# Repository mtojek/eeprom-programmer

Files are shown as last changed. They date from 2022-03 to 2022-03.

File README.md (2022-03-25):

# eeprom-programmer
EEPROM programmer based on Arduino

This repository contains Kicad schematics and .ino source files to build the EEPROM programmer using Arduino UNO R3. If you are following the Ben's Eater course to [build a 6502 computer](https://eater.net/6502), you will see that Ben uses a [TL866 II Plus](https://eater.net/6502) model, but it is possible to program memory chips using this homebrew board.

## Sample output

Check Arduino serial monitor to see memory content:

```
Reset
Run!
0000: a9 ff 8d 02 60 a9 50 8d    00 60 6a 8d 00 60 4c 0a    ⸮⸮⸮`⸮P⸮ 
0010: 80 00 00 00 00 00 00 00    00 00 00 00 00 00 00 00    ⸮
0020: 00 00 00 00 00 00 00 00    00 00 00 00 00 00 00 00    
...
7fc0: 00 00 00 00 00 00 00 00    00 00 00 00 00 00 00 00    
7fd0: 00 00 00 00 00 00 00 00    00 00 00 00 00 00 00 00    
7fe0: 00 00 00 00 00 00 00 00    00 00 00 00 00 00 00 00    
7ff0: 00 00 00 00 00 00 00 00    00 00 00 00 00 80 00 00    
```

## Kicad preview

<p float="left">
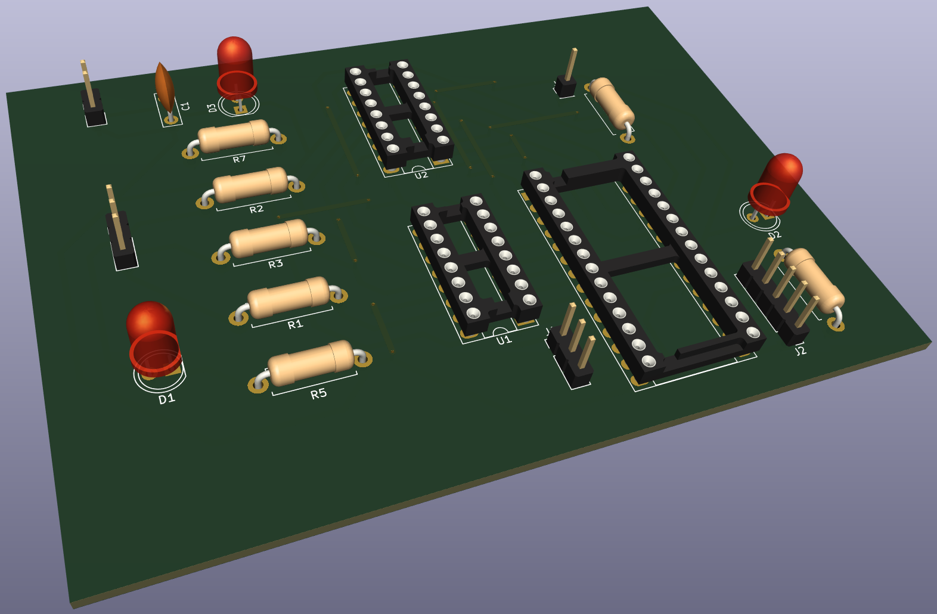
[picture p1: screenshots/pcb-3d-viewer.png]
  
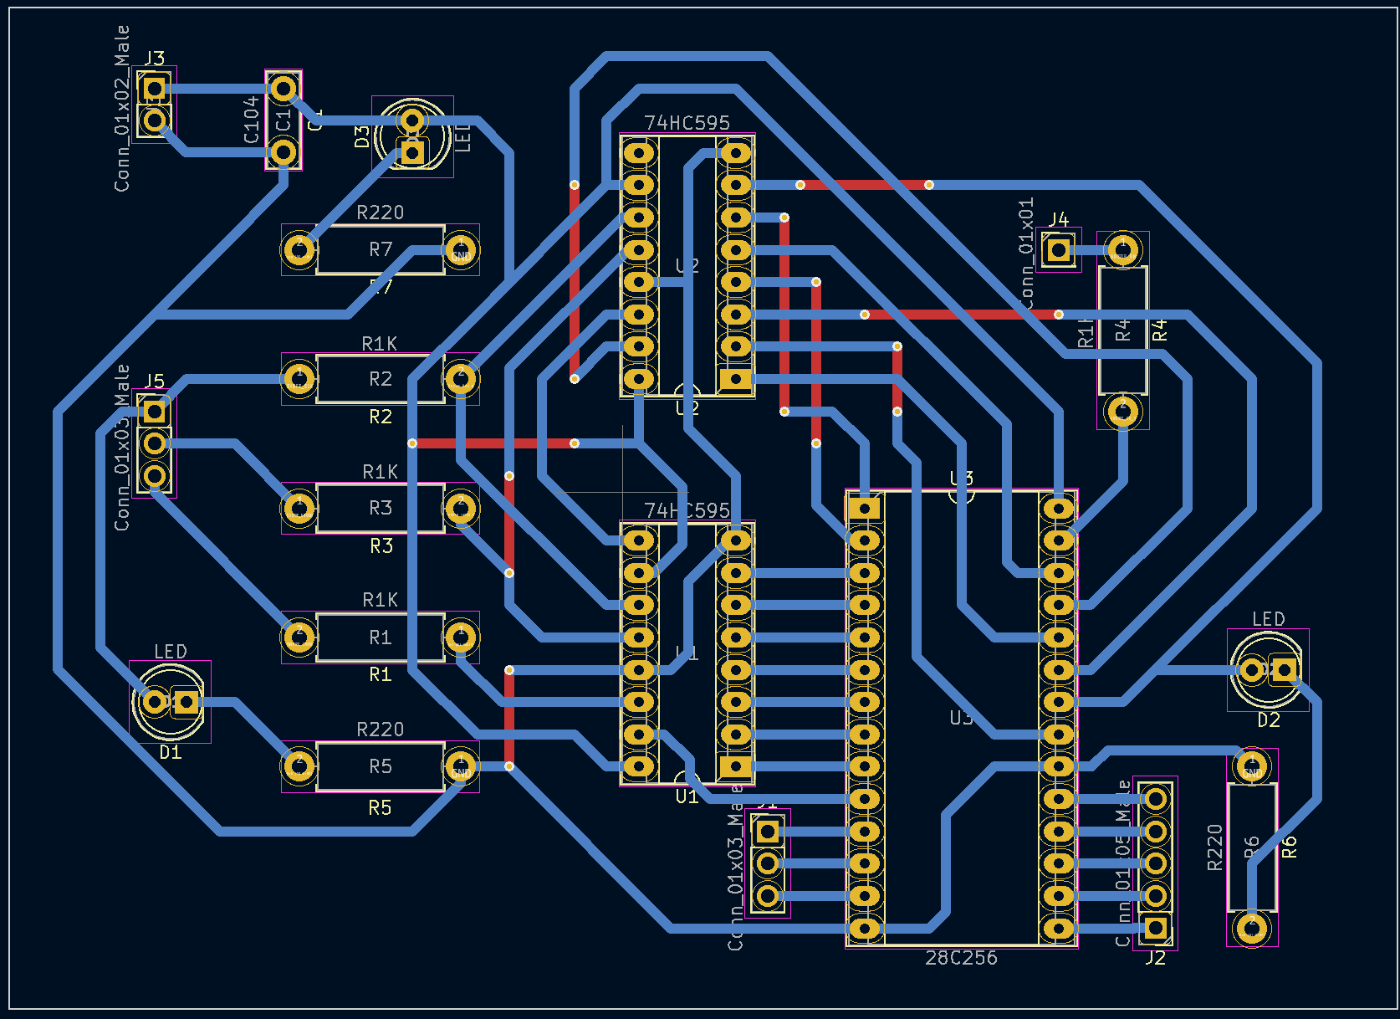
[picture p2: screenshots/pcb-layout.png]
  
</p>

## Photos

<p float="left">
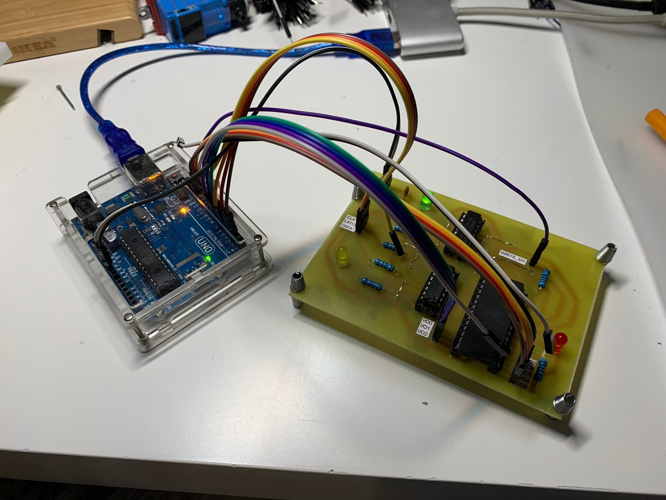
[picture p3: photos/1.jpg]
  
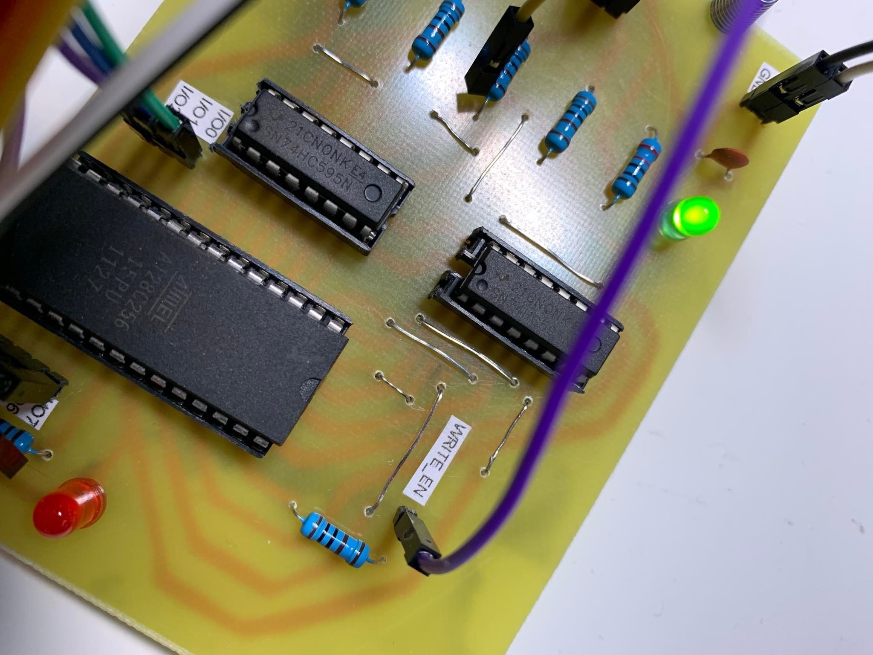
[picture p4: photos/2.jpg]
  
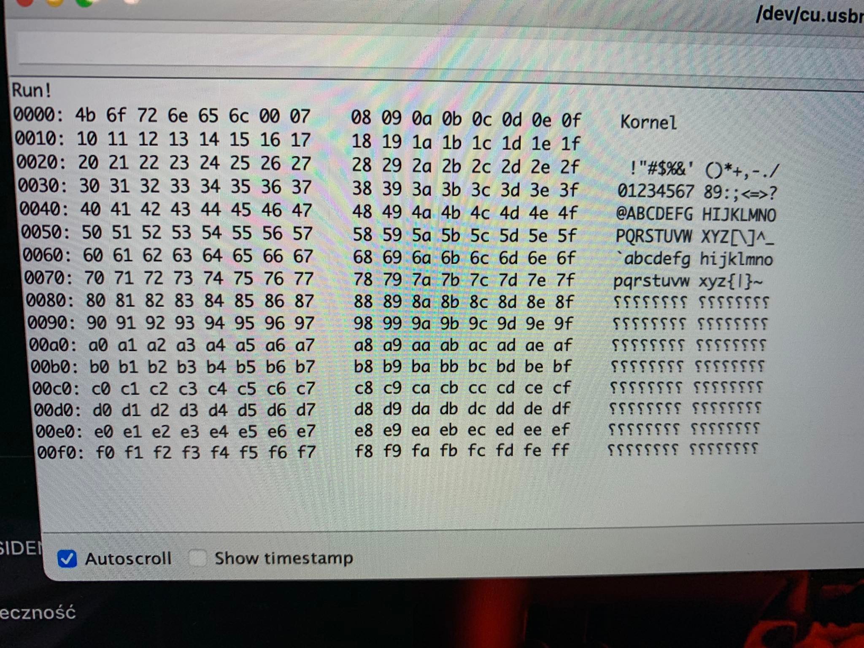
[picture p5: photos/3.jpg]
  
</p>

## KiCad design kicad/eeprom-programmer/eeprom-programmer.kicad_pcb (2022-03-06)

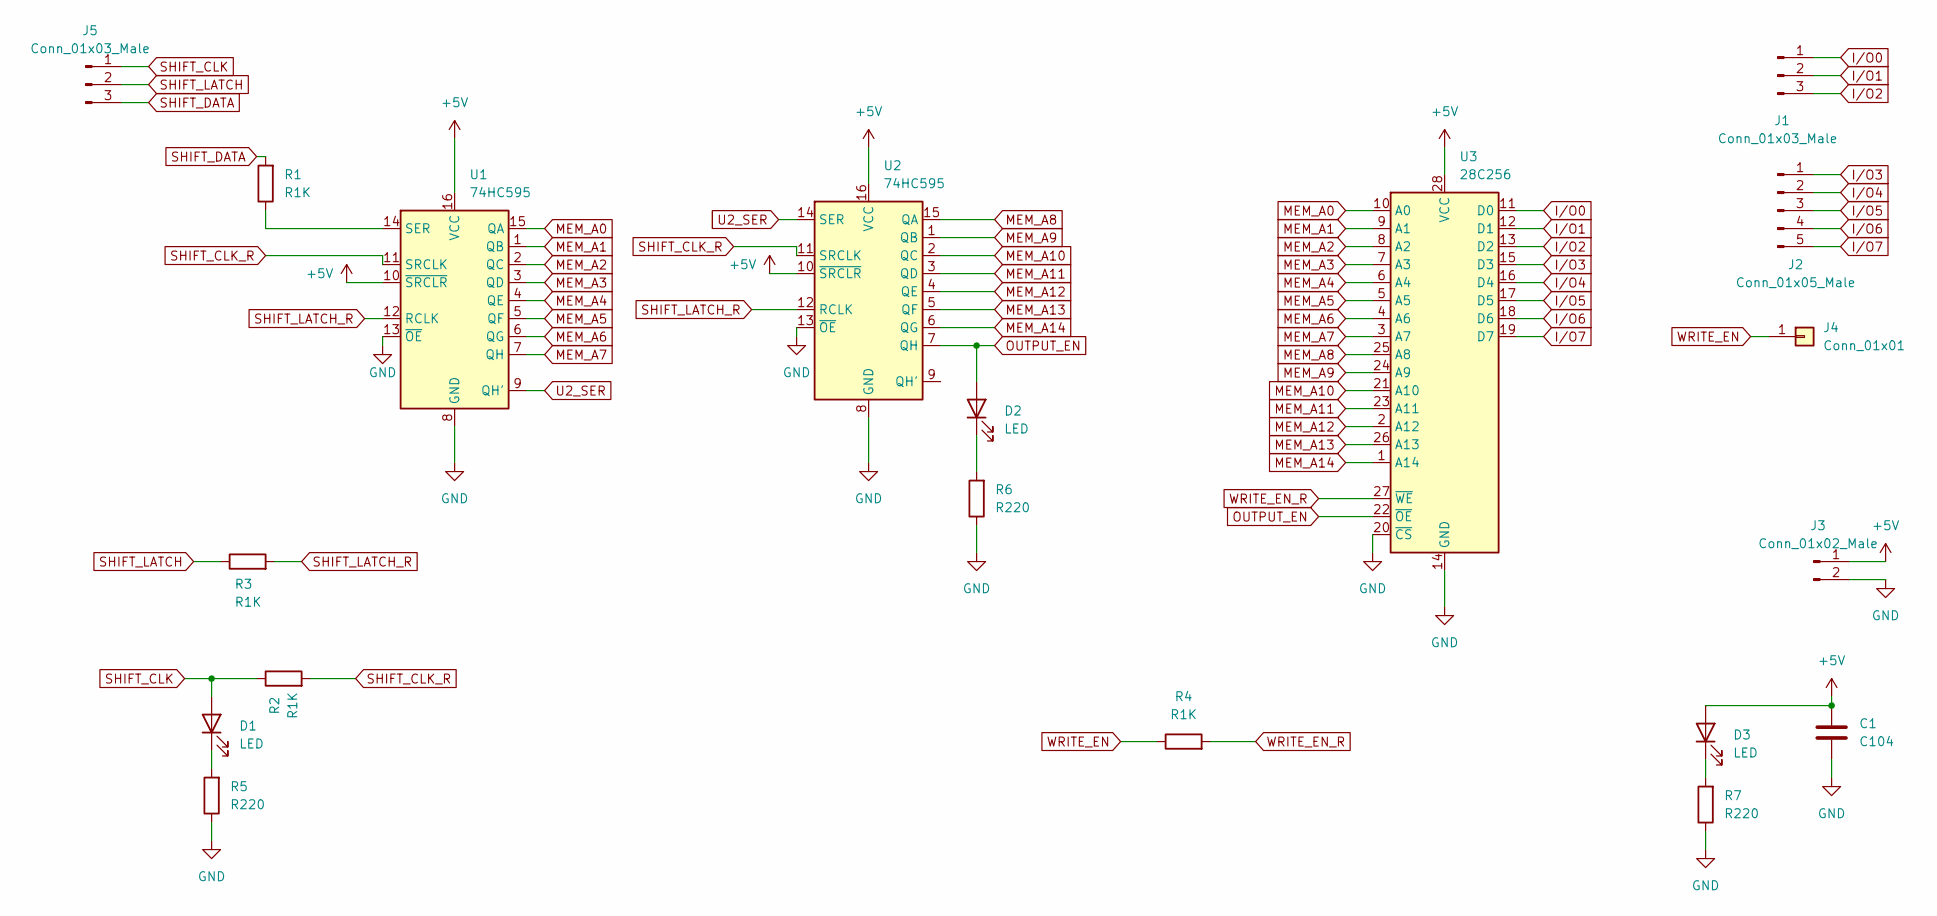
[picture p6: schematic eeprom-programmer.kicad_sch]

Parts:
C1: C104; C_Disc_D7.5mm_W2.5mm_P5.00mm
D1, D2, D3: LED; LED_D5.0mm
J1, J5: Conn_01x03_Male; PinHeader_1x03_P2.54mm_Vertical
J2: Conn_01x05_Male; PinHeader_1x05_P2.54mm_Vertical
J3: Conn_01x02_Male; PinHeader_1x02_P2.54mm_Vertical
J4: Conn_01x01; PinHeader_1x01_P2.54mm_Vertical
R1, R2, R3, R4: R1K; R_Axial_DIN0411_L9.9mm_D3.6mm_P12.70mm_Horizontal
R5, R6, R7: R220; R_Axial_DIN0411_L9.9mm_D3.6mm_P12.70mm_Horizontal
U1, U2: 74HC595; DIP-16_W7.62mm_Socket_LongPads
U3: 28C256; DIP-28_W15.24mm_Socket_LongPads

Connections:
+5V: C1.1, D3.2 (A), J3.1, U1.10 (~SRCLR), U1.16 (VCC), U2.10 (~SRCLR), U2.16 (VCC), U3.28 (VCC)
GND: C1.2, J3.2, R5.1, R6.1, R7.1, U1.8 (GND), U1.13 (~OE), U2.8 (GND), U2.13 (~OE), U3.14 (GND), U3.20 (~CS)
I/O0: J1.1, U3.11 (D0)
I/O1: J1.2, U3.12 (D1)
I/O2: J1.3, U3.13 (D2)
I/O3: J2.1, U3.15 (D3)
I/O4: J2.2, U3.16 (D4)
I/O5: J2.3, U3.17 (D5)
I/O6: J2.4, U3.18 (D6)
I/O7: J2.5, U3.19 (D7)
MEM_A0: U1.15 (QA), U3.10 (A0)
MEM_A1: U1.1 (QB), U3.9 (A1)
MEM_A2: U1.2 (QC), U3.8 (A2)
MEM_A3: U1.3 (QD), U3.7 (A3)
MEM_A4: U1.4 (QE), U3.6 (A4)
MEM_A5: U1.5 (QF), U3.5 (A5)
MEM_A6: U1.6 (QG), U3.4 (A6)
MEM_A7: U1.7 (QH), U3.3 (A7)
MEM_A8: U2.15 (QA), U3.25 (A8)
MEM_A9: U2.1 (QB), U3.24 (A9)
MEM_A10: U2.2 (QC), U3.21 (A10)
MEM_A11: U2.3 (QD), U3.23 (A11)
MEM_A12: U2.4 (QE), U3.2 (A12)
MEM_A13: U2.5 (QF), U3.26 (A13)
MEM_A14: U2.6 (QG), U3.1 (A14)
unnamed: D1.1 (K), R5.2
unnamed: D3.1 (K), R7.2
unnamed: D2.1 (K), R6.2
unnamed: R1.1, U1.14 (SER)
OUTPUT_EN: D2.2 (A), U2.7 (QH), U3.22 (~OE)
SHIFT_CLK: D1.2 (A), J5.1, R2.1
SHIFT_CLK_R: R2.2, U1.11 (SRCLK), U2.11 (SRCLK)
SHIFT_DATA: J5.3, R1.2
SHIFT_LATCH: J5.2, R3.1
SHIFT_LATCH_R: R3.2, U1.12 (RCLK), U2.12 (RCLK)
U2_SER: U1.9 (QH'), U2.14 (SER)
WRITE_EN: J4.1, R4.1
WRITE_EN_R: R4.2, U3.27 (~WE)

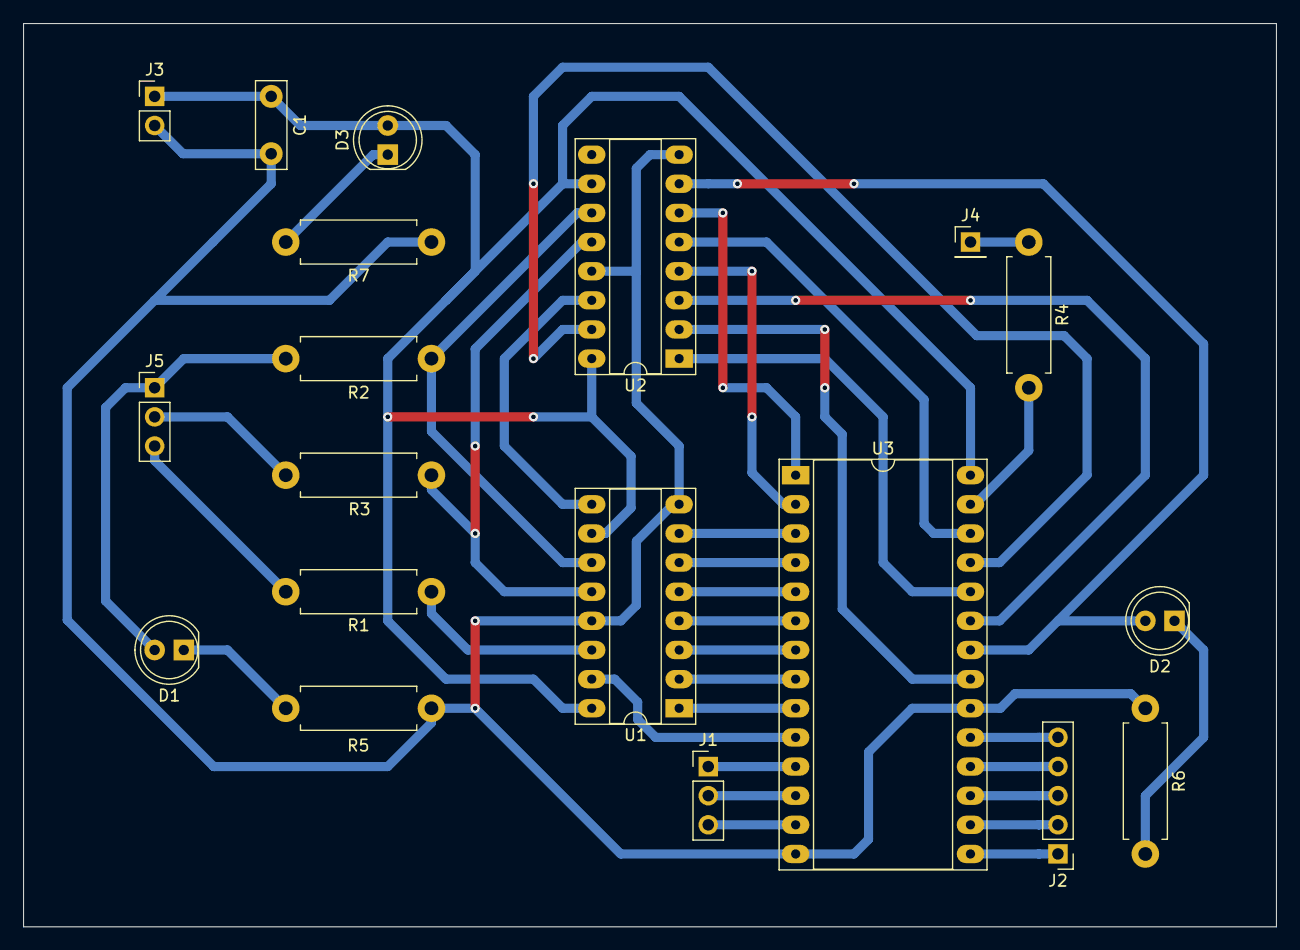
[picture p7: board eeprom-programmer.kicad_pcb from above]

Board: 2 copper layers, 109.2 x 78.7 mm, 19 parts (0 on the bottom side), 38 nets.

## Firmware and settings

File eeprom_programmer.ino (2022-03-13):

#define SHIFT_CLK 2
#define SHIFT_LATCH 3
#define SHIFT_DATA 4

#define EEPROM_D0 5
#define EEPROM_D7 12

#define WRITE_EN 13

#define OPCODE_BRK 0

void setAddress(unsigned int address, bool outputEnable) {
  digitalWrite(SHIFT_LATCH, LOW);
  shiftOut(SHIFT_DATA, SHIFT_CLK, MSBFIRST, (address >> 8) | (outputEnable ? 0 : 0x80));
  shiftOut(SHIFT_DATA, SHIFT_CLK, MSBFIRST, address);
  digitalWrite(SHIFT_LATCH, HIGH);
  digitalWrite(SHIFT_LATCH, LOW);
}

byte readEEPROM(unsigned int address) {
  for (int pin = EEPROM_D0; pin <= EEPROM_D7; pin += 1) {
    pinMode(pin, INPUT);
  }

  setAddress(address, true);
  byte data = 0;
  for (int pin = EEPROM_D7; pin >= EEPROM_D0; pin -= 1) {
    data = (data << 1) + digitalRead(pin);
  }
  return data;
}

byte writeEEPROM(unsigned int address, byte data) {
  for (int pin = EEPROM_D0; pin <= EEPROM_D7; pin += 1) {
    pinMode(pin, OUTPUT);
  }

  setAddress(address, false);
  for (int pin = EEPROM_D0; pin <= EEPROM_D7; pin += 1) {
    digitalWrite(pin, data & 1);
    data = data >> 1;
  }
  digitalWrite(WRITE_EN, LOW);
  delayMicroseconds(1);
  digitalWrite(WRITE_EN, HIGH);
  delay(10);
}

void printContents(unsigned int offset, unsigned int len) {
  for (unsigned int base = offset; base <= offset + len; base += 16) {
    byte data[16];
    for (unsigned int offset = 0; offset < 16; offset += 1) {
      data[offset] = readEEPROM(base + offset);
    }

    char buf[80];
    sprintf(buf, "%04x: %02x %02x %02x %02x %02x %02x %02x %02x    %02x %02x %02x %02x %02x %02x %02x %02x    %c%c%c%c%c%c%c%c %c%c%c%c%c%c%c%c",
            base,
            data[0], data[1], data[2], data[3], data[4], data[5], data[6], data[7], data[8], data[9], data[10], data[11], data[12], data[13], data[14], data[15],
            data[0], data[1], data[2], data[3], data[4], data[5], data[6], data[7], data[8], data[9], data[10], data[11], data[12], data[13], data[14], data[15]);
    Serial.println(buf);
  }
}

void setup() {
  pinMode(SHIFT_CLK, OUTPUT);
  pinMode(SHIFT_LATCH, OUTPUT);
  pinMode(SHIFT_DATA, OUTPUT);

  digitalWrite(WRITE_EN, HIGH);
  pinMode(WRITE_EN, OUTPUT);

  Serial.begin(57600);

  Serial.println("Reset");
  delay(2000);
  Serial.println("Run!");

  unsigned int offset = 0;
  /*char program[] = {0xa9, 0xff, 0x8d, 0x02, 0x60, 0xa9, 0x50, 0x8d, 0x00, 0x60, 0x6a, 0x8d, 0x00, 0x60, 0x4c, 0x0a,
                    0x80};
    const int programLen = 17;

    for (offset = 0; offset <= programLen; offset++) {
    writeEEPROM(offset, program[offset]);
    }*/

  // Fill empty bytes
  /*for (offset = 0x7f00; offset < 0x7ffc; offset++) {
    writeEEPROM(offset, OPCODE_BRK);
    }*/

  // Write vector
  /*writeEEPROM(0x7ffc, 0x00);
    writeEEPROM(0x7ffd, 0x80);
    writeEEPROM(0x7ffe, 0x00);
    writeEEPROM(0x7fff, 0x00);*/

  printContents(0, 0xff);
  printContents(0x7f00, 0xff);
}


void loop() {
  // put your main code here, to run repeatedly:

}

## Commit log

2022-02-27 Kicad WIP
    [eeprom-programmer.kicad_pcb, eeprom-programmer.kicad_sch]
2022-03-06 PCB ready
    [eeprom-programmer.kicad_pcb, eeprom-programmer.kicad_sch]
2022-03-06 PCB polished
    [eeprom-programmer.kicad_pcb]
